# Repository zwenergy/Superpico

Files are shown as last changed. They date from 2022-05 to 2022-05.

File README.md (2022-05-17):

# Superpico
A Raspberry Pi Pico-based Supervision Flash Cart

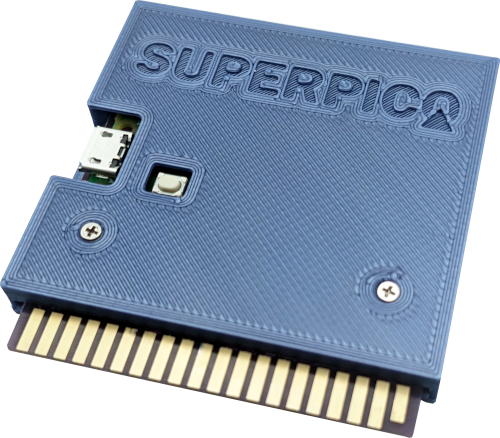
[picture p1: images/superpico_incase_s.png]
Superpico


This is an RP2040-based flash cartridge for the Watara Supervision handheld.
The RP2040 acts as the ROM chip of the cart.
The cartridge can hold one game at a time.

## Software Side
In order to load a game onto the cartridge, you first have a "convert" a ROM to a UF2 file.

**Requirements:**
1. Python
2. CMake
3. RP2040 C SDK installed and paths set up

### Single ROM
Steps:

1. Use the bin2c.py script to convert a ROM file to a C-array. Usage: `bin2c.py ROMFILE rom.h`. Place the genereated `rom.h` file in the root of code directory, beside main.c.
2. Run `make` in the code directory.
3. Connect the Raspberry Pi Pico to the computer while holding down the BOOTSEL button.
4. Drag and drop the newly generated .uf2 file onto the Pico.

### Batch Conversion
You can convert several ROMs at once by using the `batch.py` script.
Steps:

1. Place the (extracted) ROMs into the batch/ROM folder.
2. Run the `batch.py` script.
3. After a short time, the generated .uf2 files should be in the uf2 folder.

## Hardware Side
### BOM
| Component | Amount | 
|---|---|
|Raspberry Pi Pico | 1 |
|74LVC245AT20 | 3 |

### PCB
The PCB can be ordered using the Gerber files. A width of **1.0 mm or 1.2 mm** should be chosen with ENIG surface.

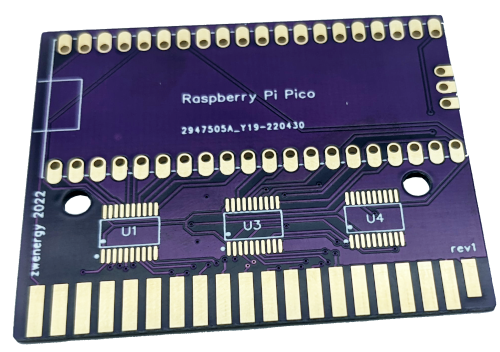
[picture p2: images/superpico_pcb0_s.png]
PCB0


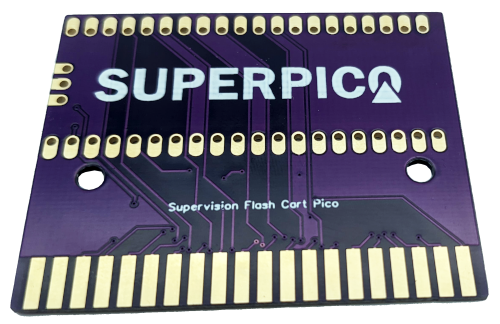
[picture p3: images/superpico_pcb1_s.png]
PCB1


## Disclaimer
**Use the files and/or schematics to build your own board at your own risk**.
This board works fine for me, but it's a simple hobby project, so there is no liability for errors in the schematics and/or board files.
**Use at your own risk**.

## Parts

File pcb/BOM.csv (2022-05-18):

ID | Name | Designator | Footprint | Quantity | Manufacturer Part | Manufacturer | Supplier | Supplier Part | Price
2 | 74LVC245AT20-13 | U1,U3,U4 | TSSOP-20_L6.5-W4.4-P0.65-LS6.4-BL | 3 | 74LVC245AT20-13 | DIODES(美台) | LCSC | C460537 | 0.341
3 | RASPBERRYPIPICO | 1 | RASPBERRYPIPICO | 1

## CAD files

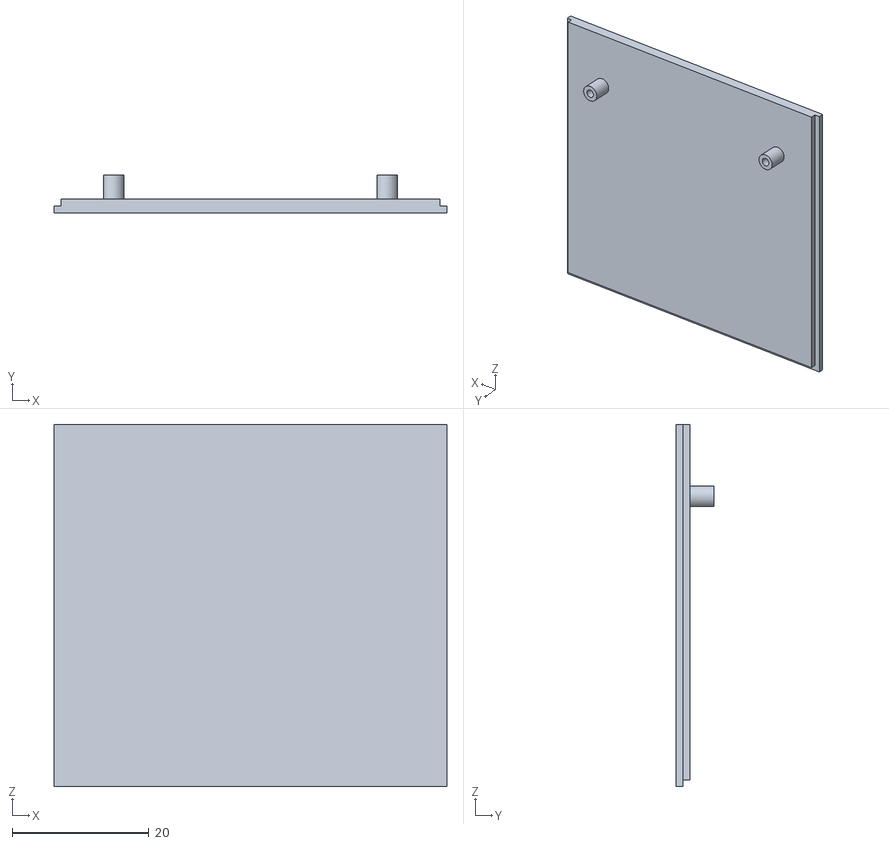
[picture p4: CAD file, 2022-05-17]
case/Superpico_Case_Bottom.stl
57.5 x 5.50 x 53.0

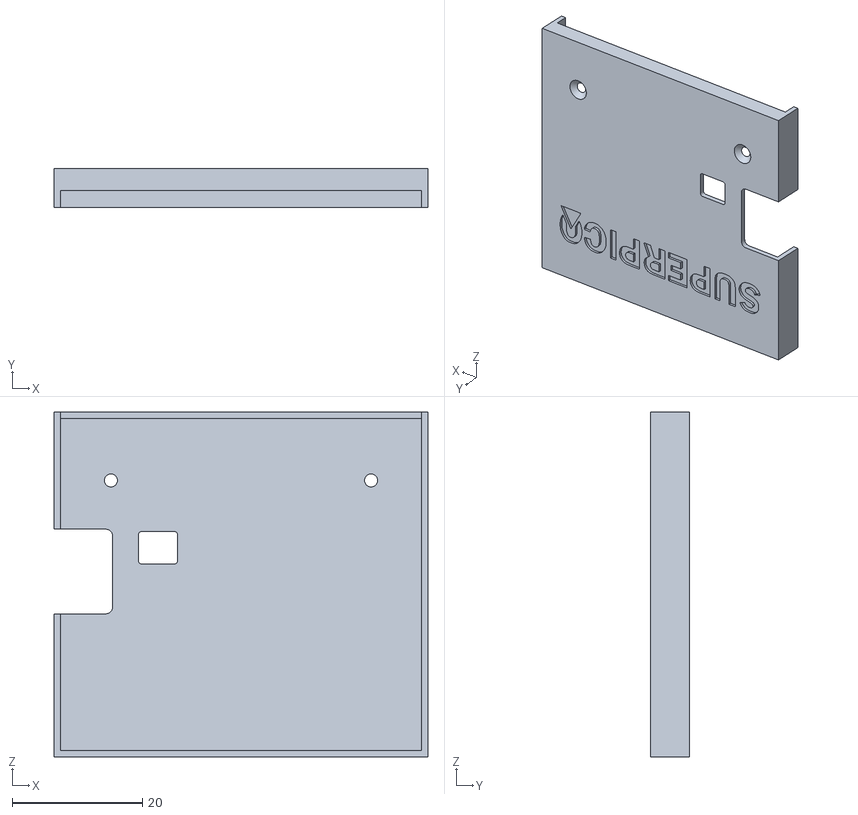
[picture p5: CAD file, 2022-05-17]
case/Superpico_Case_Top.stl
57.5 x 6.00 x 53.0

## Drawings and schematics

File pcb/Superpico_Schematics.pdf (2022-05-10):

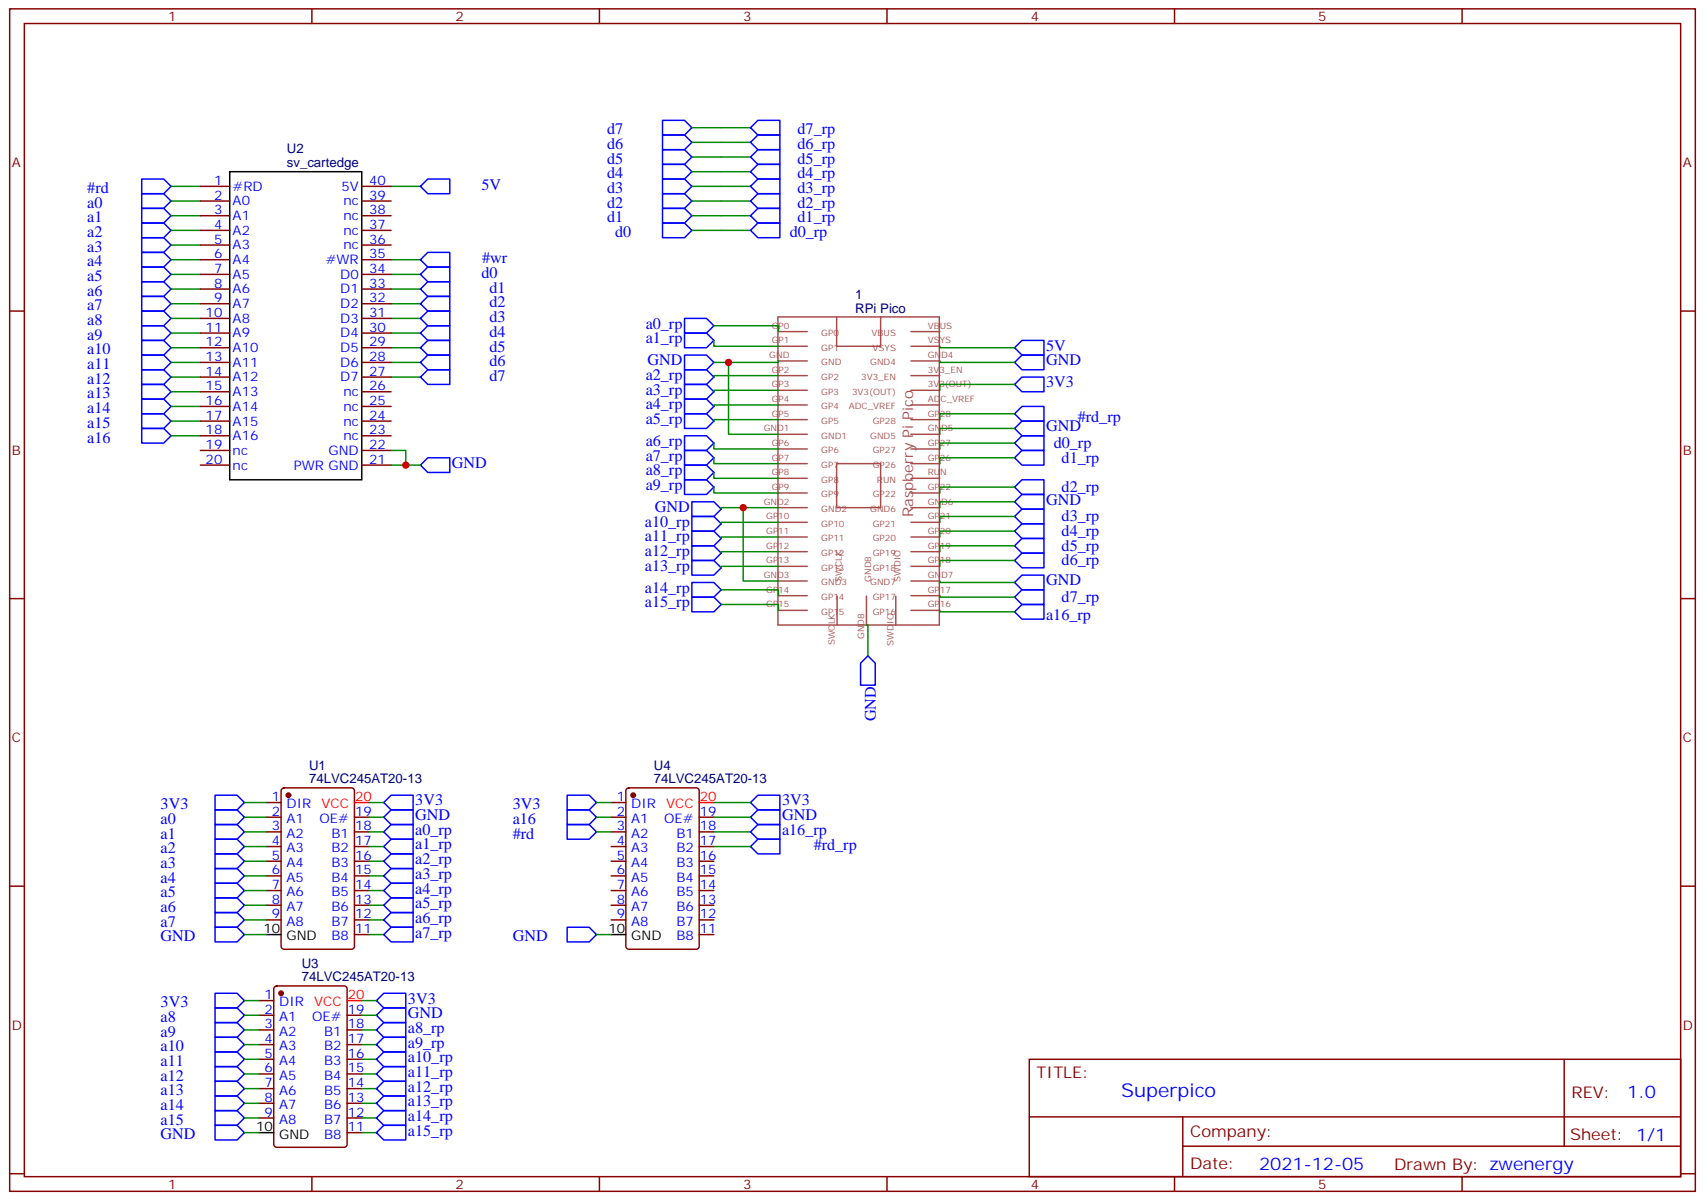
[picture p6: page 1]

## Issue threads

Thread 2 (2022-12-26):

Issues Making

ziggystar12, 2022-12-26:
I've tried a number of things, including building on Windows and On Mac. Even when CMAKE successfully completes a build, on both systems, there is no resulting .uf2 file. Just a bunch of other files. What might I be doing wrong? Could you include one sample .uf2 file in your source so that we can test the system? I've built 5 of the devices but can't test them.  I can't use batch either because I don't have the resulting superpico.uf2 file that it apparently needs. I thought it was a build environment issue until it failed the exact way on both systems.

ziggystar12, 2022-12-26:
Resolved my own issue. Apparently PICOSDK 1.3 and CMAKE 3.20 are needed.

Eljugad0r, 2024-08-04:
Is it possible that you send me your uf2 games? Cant manage to convert .sv to .uf2

Eljugad0r, 2024-08-14:
@ziggystar12
Is it possible that you send me at least one of your uf2 games? Cant manage to convert .sv to .uf2. No matter what i do

ziggystar12, 2024-08-14:
This is the only file I could find from the old project. I don’t remember what it is.

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

Eljugad0r, 2024-08-14:
@ziggystar12
First of all thank you very much
But i cant find any files in this message
Where should i look for the file?

ziggystar12, 2024-08-14:
I attached but it didn't stick. Try emailing me directly at Gmail. Same name

Get Outlook for Android<https://aka.ms/AAb9ysg>
________________________________
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

Eljugad0r, 2024-08-14:
@ziggystar12 thanks, just did

Closed 2023-02-09.

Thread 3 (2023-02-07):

Total noob on programming

NeORomani2, 2023-02-07:
Hi

Tried to do it on linux, but got errors about PICO_SDK_PATH, errors about make no targets specified...

Is there any kind soul to do it for me? I can send the rom backups of my games if needed.
Or provide an .exe file to use on windows?

thanks in advance and best regards

zwenergy, 2023-02-08:
What's the exact error? How did you setup the RP2040 SDK? What does "echo $PICO_SDK_PATH" return?

NeORomani2, 2023-02-08:
Well, I managed to make it work on batch format, for a single rom doesn't work.

I follow the guide, but when I write "make" it says "make: *** No targets specified and no makefile found"
If I write "cmake .." that I saw somewhere, it says "CMake Error: The source directory "/home/user/Superpico-main" does not appear to contain CMakeLists.txt.·

I'll let here all the steps for noobies like me, I followed all these steps to make it work.

On windows, install vmware workstation player. Tried Rocky Linux and debian and it was a nightmare, better use Ubuntu
Create a virtual machine using ubuntu-20.04.3-desktop-amd64.iso it will ask you to create a user, let's say we name it "user"

After installing copy Superpico-main.zip to any folder, vmware will install the vmware tools automatically, so you can drag and drop the file, let's say you copy and unzip it on /home/user/Super-pico main/

Also, copy some rom, let's say alien.sv to /Superpico-main/code/batch/rom

Then, write these lines in order opening an app called Terminal. Use command "cd .." (very important an space between "cd" and "..") to go one folder level up, and "ls" command to show the contents of a folder, like a "dir" in msdos

sudo -i
passwd  -> Here you will have to chose a password for root
su – root   ->Here enter the root password
apt update
apt install python3
apt install cmake
apt install -y build-essential
apt install git
apt install gcc-arm-none-eabi

The next commands I found in https://lindevs.com/set-up-raspberry-pi-pico-sdk-on-ubuntu

sudo git clone https://github.com/raspberrypi/pico-sdk.git /opt/pico-sdk
sudo git -C /opt/pico-sdk submodule update --init
echo 'export PICO_SDK_PATH=/opt/pico-sdk' | sudo tee -a /etc/profile.d/pico-sdk.sh
source /etc/profile

Then, you go to /Superpico-main/code/batch and write the following

python3 batch.py

Done! your rom in uf2 format should be inside the uf2 folder. Still didn't try the rom, because next step is trying to build the PCB, so it might not work
Wish me good luck

zwenergy, 2023-02-09:
You typically create a "build" folder and inside that build folder you'd call "cmake <SOURCEFOLDER>", where <SOURCEFOLDER> contains the CMakeLists.txt file. And then call "make" inside the build folder (that's basically what the batch.py is doing).
If there's any other problem you can re-open the issue.

Closed 2023-02-09.

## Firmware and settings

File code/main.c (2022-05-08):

#include "pico/stdlib.h"
#include <stdlib.h>
#include <stdio.h>

#include "rom.h"

// Pin Definitions.
#define A0 0
#define A1 1
#define A2 2
#define A3 3
#define A4 4
#define A5 5
#define A6 6
#define A7 7
#define A8 8
#define A9 9
#define A10 10
#define A11 11
#define A12 12
#define A13 13
#define A14 14
#define A15 15
#define A16 16
#define D0 27
#define D1 26
#define D2 22
#define D3 21
#define D4 20
#define D5 19
#define D6 18
#define D7 17
#define NWR 28

#define DATAOFFSETLOW 17
#define DATAOFFSETHIGH 20

// Bit masks
#define DATAMASK 0b01100011111100000000000000000
#define READMASK 0b10000000000000000000000000000

void initGPIO() {
  // Set pin directions.
  gpio_init( A0 );
  gpio_set_dir( A0, GPIO_IN );
  gpio_init( A1 );
  gpio_set_dir( A1, GPIO_IN );
  gpio_init( A2 );
  gpio_set_dir( A2, GPIO_IN );
  gpio_init( A3 );
  gpio_set_dir( A3, GPIO_IN );
  gpio_init( A4 );
  gpio_set_dir( A4, GPIO_IN );
  gpio_init( A5 );
  gpio_set_dir( A5, GPIO_IN );
  gpio_init( A6 );
  gpio_set_dir( A6, GPIO_IN );
  gpio_init( A7 );
  gpio_set_dir( A7, GPIO_IN );
  gpio_init( A8 );
  gpio_set_dir( A8, GPIO_IN );
  gpio_init( A9 );
  gpio_set_dir( A9, GPIO_IN );
  gpio_init( A10 );
  gpio_set_dir( A10, GPIO_IN );
  gpio_init( A11 );
  gpio_set_dir( A11, GPIO_IN );
  gpio_init( A12 );
  gpio_set_dir( A12, GPIO_IN );
  gpio_init( A13 );
  gpio_set_dir( A13, GPIO_IN );
  gpio_init( A14 );
  gpio_set_dir( A14, GPIO_IN );
  gpio_init( A15 );
  gpio_set_dir( A15, GPIO_IN );
  gpio_init( A16 );
  gpio_set_dir( A16, GPIO_IN );
  
  gpio_init( NWR );
  gpio_set_dir( NWR, GPIO_IN );

  // Initially, set the pins to IN
  gpio_init( D0 );
  gpio_set_dir( D0, GPIO_IN );
  gpio_init( D1 );
  gpio_set_dir( D1, GPIO_IN );
  gpio_init( D2 );
  gpio_set_dir( D2, GPIO_IN );
  gpio_init( D3 );
  gpio_set_dir( D3, GPIO_IN );
  gpio_init( D4 );
  gpio_set_dir( D4, GPIO_IN );
  gpio_init( D5 );
  gpio_set_dir( D5, GPIO_IN );
  gpio_init( D6 );
  gpio_set_dir( D6, GPIO_IN );
  gpio_init( D7 );
  gpio_set_dir( D7, GPIO_IN );
  
}

int main() {
  set_sys_clock_khz(250000, false);
  
  initGPIO();
  
  // Read.
  while ( 1 ) {
    unsigned int data = gpio_get_all();
    unsigned int oe = !( data & READMASK );
    (oe ? gpio_set_dir_out_masked( DATAMASK ) : gpio_set_dir_in_masked( DATAMASK ) );
    
    unsigned int address = data & ADDRMASK;
    uint8_t romByte = rom[ address ];
    unsigned int gpioByte = ( ( romByte & 0b00111111 ) << DATAOFFSETLOW ) |
						  ( ( romByte & 0b11000000 ) << DATAOFFSETHIGH );
				 
    gpio_put_all( gpioByte );
  }
  
  return 0;
}

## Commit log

2022-05-10 Added schematics and gerbers.
2022-05-17 Added case files.
    [Superpico_Case_Bottom.stl, Superpico_Case_Top.stl]
2022-05-18 Added BOM and Pick & Place files.
    [BOM.csv, PickAndPlace.csv]
